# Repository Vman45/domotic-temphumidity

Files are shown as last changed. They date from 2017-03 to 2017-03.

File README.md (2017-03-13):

<!-- TOC depthFrom:1 depthTo:6 withLinks:1 updateOnSave:1 orderedList:0 -->

- [domotic-temphumidity](#domotic-temphumidity)
	- [Description](#description)
	- [Matériel:](#matriel)
	- [Architecture](#architecture)
	- [TODO:](#todo)
		- [Sauvegarde des mesures](#sauvegarde-des-mesures)
		- [Améliorations:](#amliorations)
			- [Home Assistant:](#home-assistant)
				- [automate](#automate)
			- [WeMos D1 Mini:](#wemos-d1-mini)
				- [Consommation d'énergie - deep sleep](#consommation-dnergie-deep-sleep)
				- [Tension de la batterie](#tension-de-la-batterie)
				- [Ajouter Heat Index et Dew Point](#ajouter-heat-index-et-dew-point)
				- [MQTT](#mqtt)
	- [Quelques sources:](#quelques-sources)
	- [Installation stack TICK sur Raspberry Pi 3](#installation-stack-tick-sur-raspberry-pi-3)
		- [Telegraf](#telegraf)
		- [InfluxDB](#influxdb)
		- [Chonograph](#chonograph)
		- [kapacitor](#kapacitor)
	- [Installation de Grafana](#installation-de-grafana)

<!-- /TOC -->

# domotic-temphumidity
## Description
Projet de "domotique" pour prise de température/humidité dans différentes pièces (et à l'extérieur).

## Matériel:
* `WeMos D1 mini v2`
* `DHT22` (module précâblé)
* `DS18B20` (module précâblé)
* Résistances pour _pont diviseur_: `1 KOhms` (R1) et `220 Ohms` (R2)
* 2 batteries de 3.7v type `18650 lithium-ion`
* `battery holder` à 2 emplacements pour batteries 18650
* [ optionel: `WeMos D1 Mini Single Lithium Battery Charging And Battery Boost Shield` ]
* [ optionel (avec shield ci-dessus): `Micro 1.25mm 2-Pin Female Connector Plug` ]

## Architecture
Les mesures sont envoyées vers un _MQTT broker_ (`Mosquitto`) dans différents _topics_.
Les _topics_ de ce broker sont actuellement consommés par `HomeAssistant`.
Les données sont également sauvegardées dans une _TSDB_ (InfluxDB) par `HomeAssistant`.

## TODO:
### Sauvegarde des mesures
La sauvegarde des données dans `InfluxDB` sera revue car `HomeAssistant` ne pousse des données que s'il y a un changement d'état; autrement dit plusieurs valeurs identiques consécutives ne représentent qu'un point de mesure (le 1ier) dans `InfluxDB`.
Idée à mettre en oeuvre:
* utiliser `Telegraf` pour consommer les _topics MQTT_ et pousser les mesures dans `InfluxDB`.
* désactiver le lien entre `HomeAssistant` et `InfluxDB` (config de `HomeAssistant`).

### Améliorations:
#### Home Assistant:
##### automate
Si le service `Updater` détecte une mise à jour disponible, une notification sera crée par le service `notify.notify`.
Si la tension de la batterie est inférieur au seuil configuré, une notification sera envoyée par le service `notifiy.pushbullet` à (par défaut) tous les _devices_ définis dans `PushBullet`.

#### WeMos D1 Mini:
##### Consommation d'énergie - deep sleep
Mettre le WeMos en _deep sleep_ entre 2 prises de mesure.  !! Attention câblage à ajouter entre `RST` et `D0` (aka `GPIO16`) pour permettre l'éveil) !!
Ne pas oublier d'ajouter cette ligne dans la fonction `setup`:
```
  // Connect D0 to RST to wake up
  pinMode(D0, WAKEUP_PULLUP);
```
et bien entendu dans la fonction `loop`:
```
  // convert to microseconds
  ESP.deepSleep(sleepSeconds * 1000000);
```

##### Tension de la batterie
* Mettre le WeMos en _deep sleep_ plus longtemps si le seuil `X` est atteint.
* Si le seuil `Y` (`X > Y`) est atteint soit mettre le WeMos en _deep sleep_ encore lus longtemps soit stopper (si possible) le WeMos.

##### Ajouter Heat Index et Dew Point
* ajouter la lecture ou le calcul de l'index de température (température ressentie)
* ajouter la lecture ou le calcul du point de rosée ()
Voir les articles:
 - http://www.best-microcontroller-projects.com/dht22.html
 - https://github.com/adafruit/DHT-sensor-library/blob/master/examples/DHTtester/DHTtester.ino
 - https://github.com/adafruit/DHT-sensor-library/blob/master/DHT.cpp
 - https://forums.adafruit.com/viewtopic.php?f=25&t=30241#p167348

##### MQTT
Actuellement, chaque mesure est envoyée dans un topic dédié (ex: température du living dans `home/livingroom/temperature`) ce qui se traduit par 3 _publish_ (température, humidité et tension de la batterie).
Améliorations possibles:
* soit regrouper l'envoi de ces 3 mesures dans 1 seul _topic_ (ex: `home/livingroom`) et ensuite décomposer le message en 3 dans `HomeAssistant`.
* soit revoir la nomenclature des _topics_ en y ajoutant un niveau supplémentaire: l'_étage_ (ex: `home/groundfloor/livingroom/temperature`).  Source: http://www.hivemq.com/blog/mqtt-essentials-part-5-mqtt-topics-best-practices

## Quelques sources:
* mon ami Tixu: https://github.com/tixu
* Mesure de la tension: http://www.projetsdiy.fr/mesurer-tension-alimentation-batterie-esp8266-arduino/#.WMXEVlXhCHs
* Utilisation d'un DHT22: http://www.projetsdiy.fr/esp8266-dht22-mqtt-projet-objet-connecte/#.WMXDn1XhCHu
* Utilisation d'un DS18B20: http://www.esp8266learning.com/wemos-mini-ds18b20-temperature-sensor-example.php
* InfluxDB et Telegraf sur Raspberry Pi: http://padcom13.blogspot.be/2015/12/influxdb-telegraf-and-grafana-on.html
* Packages officiels TICK pour ARM:
 - https://dl.influxdata.com/telegraf/releases/telegraf_1.2.1_armhf.deb
 - https://dl.influxdata.com/influxdb/releases/influxdb_1.2.1_armhf.deb
 - https://dl.influxdata.com/chronograf/releases/chronograf_1.2.0~beta4_armhf.deb
 - https://dl.influxdata.com/kapacitor/releases/kapacitor_1.2.0_armhf.deb
* Grafana on Raspberry Pi: https://github.com/fg2it/grafana-on-raspberry

## Installation stack TICK sur Raspberry Pi 3
### Telegraf
```
wget https://dl.influxdata.com/telegraf/releases/telegraf_1.2.1_armhf.deb
sudo dpkg -i telegraf_1.2.1_armhf.deb
```
### InfluxDB
```
wget https://dl.influxdata.com/influxdb/releases/influxdb_1.2.1_armhf.deb
sudo dpkg -i influxdb_1.2.1_armhf.deb
```
### Chonograph
```
wget https://dl.influxdata.com/chronograf/releases/chronograf_1.2.0~beta4_armhf.deb
sudo dpkg -i chronograph_1.2.0~beta4_armhf.deb
```
### kapacitor
```
wget https://dl.influxdata.com/kapacitor/releases/kapacitor_1.2.0_armhf.deb
sudo dpkg -i kapacitor_1.2.0_armhf.deb
```

## Installation de Grafana
Basé sur https://github.com/fg2it/grafana-on-raspberry (releases: https://github.com/fg2it/grafana-on-raspberry/releases)
```
wget https://github.com/fg2it/grafana-on-raspberry/releases/download/v4.1.2/grafana_4.1.2-1487023783_armhf.deb
sudo dpkg -i grafana_4.1.2-1487023783_armhf.deb
sudo apt-get install -f
```

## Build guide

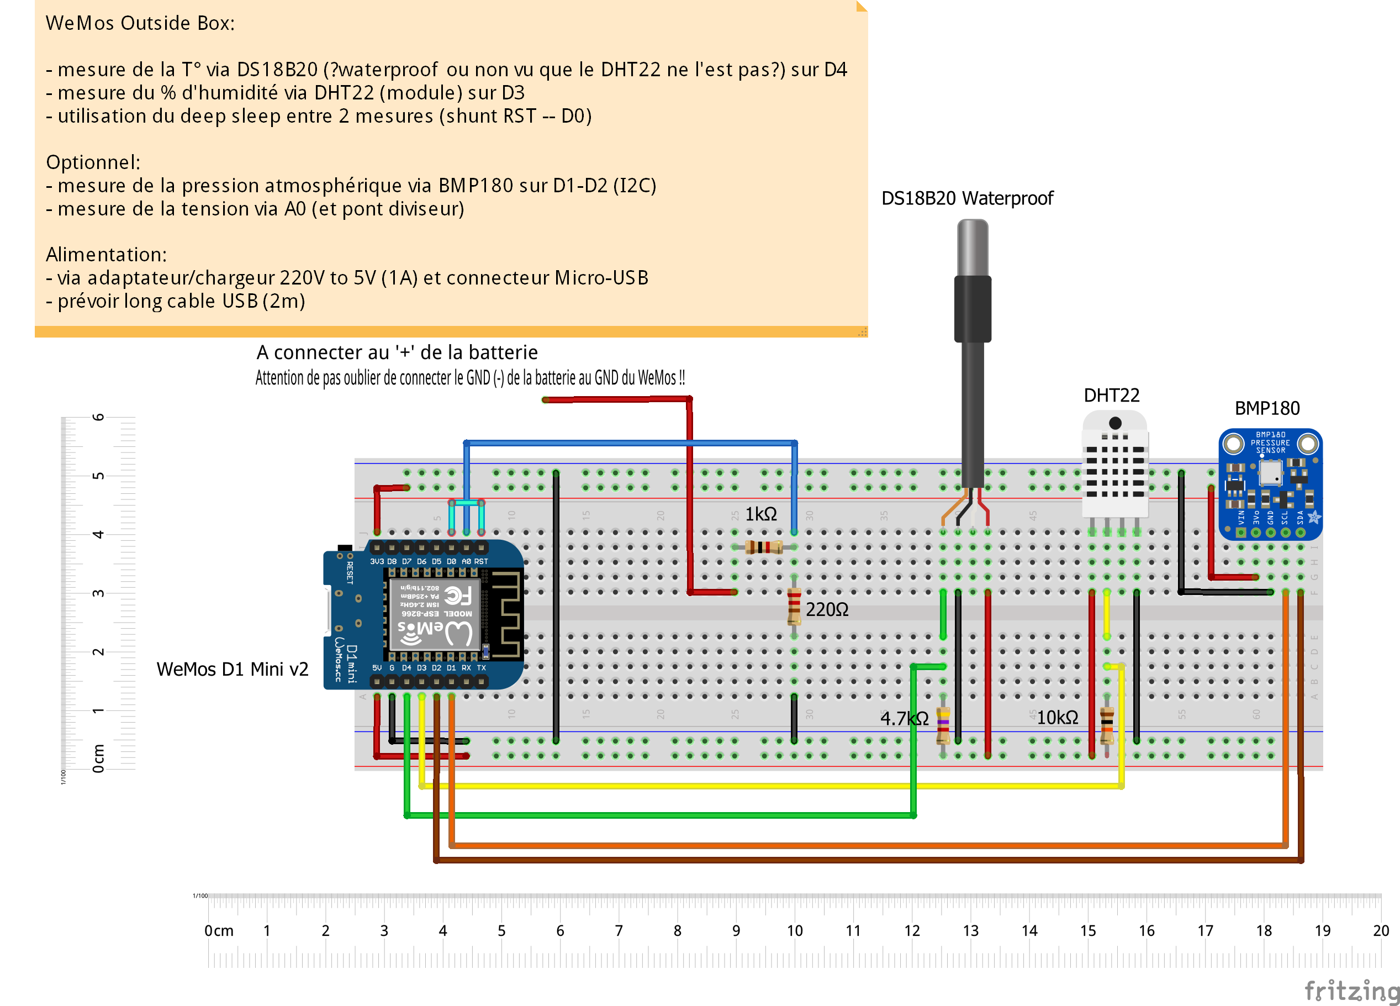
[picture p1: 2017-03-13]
wiring-outside-box.png

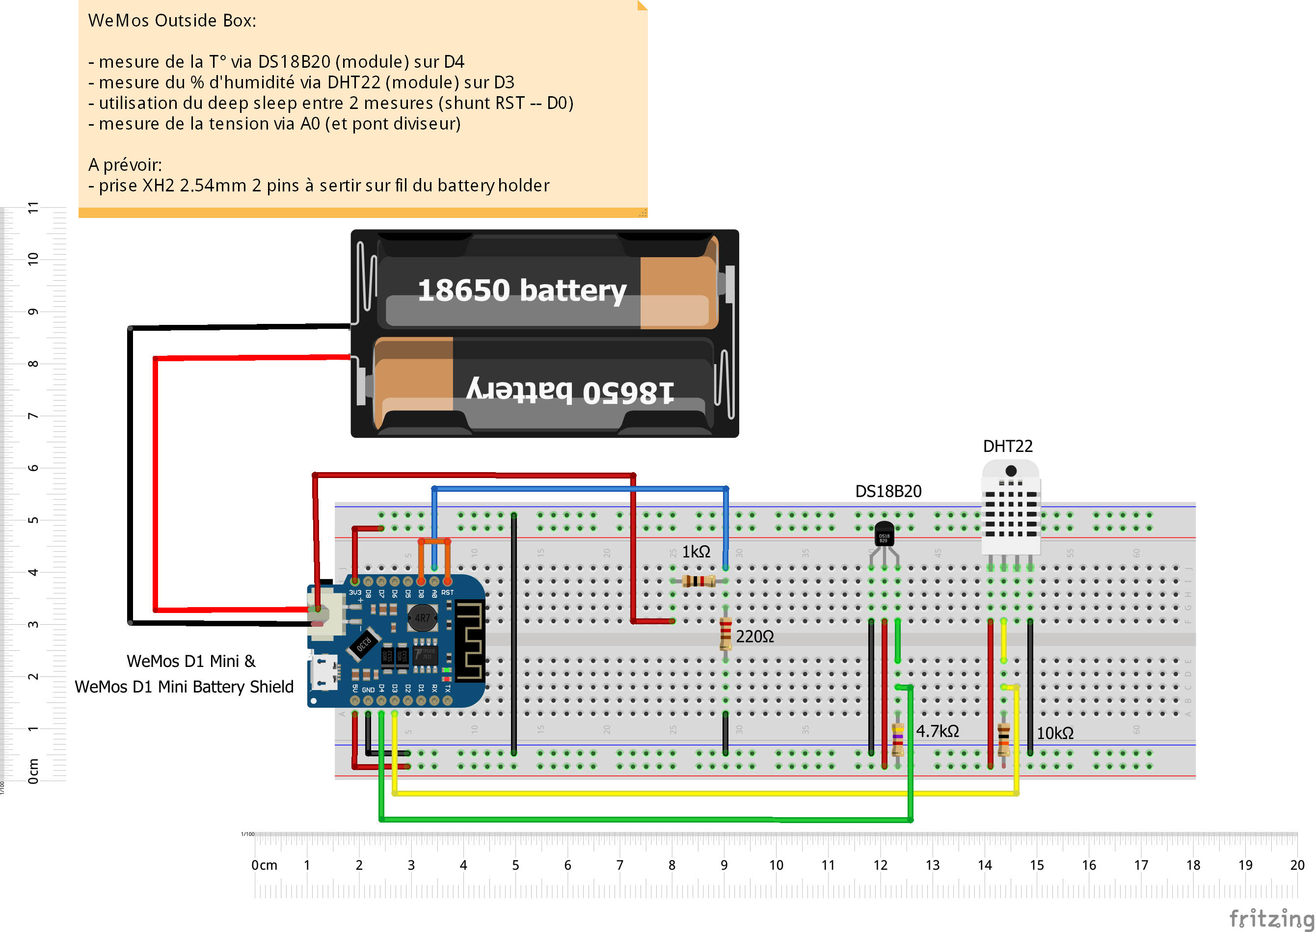
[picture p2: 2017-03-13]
wiring-inside-box.png

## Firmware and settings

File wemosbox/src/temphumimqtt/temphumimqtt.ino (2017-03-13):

// Include the libraries we need
#include <Adafruit_Sensor.h>
#include <DHT.h>

#include <OneWire.h>
#include <DallasTemperature.h>

#include <DNSServer.h>
#include <WiFiClient.h>
#include <ESP8266WebServer.h>
#include <WiFiManager.h>

#include <PubSubClient.h>

#include <ArduinoJson.h>

#define ssid     "" // WiFi SSID
#define password "" // WiFi password


// DHT Config ***************************************************************
// DHT Sensor on pin D3
#define DHTPIN D3
// Using a DHT22 sensor
#define DHTTYPE DHT22

DHT dht(DHTPIN, DHTTYPE);

// MQTT Config **************************************************************
#define mqtt_server    "192.168.1.10"
#define mqtt_port      1883
// #define mqtt_user   "mqtt_user"
// #define mqtt_pass   "mqtt_pass"
#define out_temp_topic "home/livingroom/temperature"
#define out_hum_topic  "home/livingroom/humidity"
#define out_batt_topic "home/livingroom/battery"

// DS18B20 Sensor Config *****************************************************
// Data wire is plugged into port D4 on the WeMos 
// Setup a oneWire instance to communicate with any OneWire devices (not just Maxim/Dallas temperature ICs)
OneWire oneWire(D4);

// Pass our oneWire reference to Dallas Temperature.
DallasTemperature sensors(&oneWire);

// arrays to hold device address
DeviceAddress insideThermometer;

// To handle time between 2 reads
const int sensorPolling = 30000;
unsigned long currentMillis = 0;    // stores the value of millis() in each iteration of loop()
unsigned long previousPoll = 0;   // will store last time the LED was updated

char data[80];

// ESP Config ******************************************************************
WiFiClient espClient;
PubSubClient client(espClient);

// Web server running on port
ESP8266WebServer server (80);

// Measurement *****************************************************************
// Temp
//   - DS18B20
float t = 0;
//   - DHT22
float t2 = 0;
// Humidity
//   - DHT22
float h = 0;

// Battery Voltage
//     Const
const float tMaxA0 = 3.3; // Tmax permissible by the A/D converter on pin A0
const float coeff = 0.18; // Divider bridge coeff in ohms = (R1 / (R1 + R2)) where R1 = 1Kohms and R2 220ohms
const float diff = 0.0;  // = Diff between calculation and voltmeter
//     raw value read from A/D converter
unsigned int raw = 0;
//     real voltage
float batV = 0;


// Setup function. Here we do the basics **************************************
void setup(void) {

  Serial.begin(9600);
  pinMode(BUILTIN_LED, OUTPUT);
  pinMode(A0, INPUT);
  
  Serial.println("Domotic - Temperature and Humidity sensor");
  WiFiManager wifiManager;

  // locate devices on the bus
  Serial.print("Locating devices ... ");
  sensors.begin();
  Serial.print(" Found ");
  Serial.print(sensors.getDeviceCount(), DEC);
  Serial.println(" devices.");

  // report parasite power requirements
  Serial.print("Parasite power is: ");
  if (sensors.isParasitePowerMode()) Serial.println("ON");
  else Serial.println("OFF");

  if (!sensors.getAddress(insideThermometer, 0)) Serial.println("Unable to find address for Device 0");

  Serial.print("Device 0 Address: ");
  printAddress(insideThermometer);
  Serial.println();

  // set the resolution to 9 bit (Each Dallas/Maxim device is capable of several different resolutions)
  sensors.setResolution(insideThermometer, 10);
  Serial.print("Device 0 Resolution: ");
  Serial.print(sensors.getResolution(insideThermometer), DEC);
  Serial.println();

  // Initialize DHT Sensor
  dht.begin();

  wifiManager.autoConnect(ssid, password);
  // Connexion WiFi établie / WiFi connexion is OK
  Serial.println("");
  Serial.print("Connected to "); Serial.println ( ssid );
  Serial.print("IP address: "); Serial.println ( WiFi.localIP() );

  client.setServer(mqtt_server, mqtt_port);
  client.setCallback(callback);

  // On branche la fonction qui gère la premiere page / link to the function that manage launch page
  server.on("/", handleRoot);

  server.begin();
  Serial.println("HTTP server started");
}

// *************************************************************************************************
String getPage() {

  String page = "";
  page += "<!DOCTYPE html>";
  page += "<html lang='en'>";
  page += "  <head>";
  page += "    <meta charset='utf-8'>";
  page += "    <meta http-equiv='X-UA-Compatible' content='IE=edge'>";
  page += "    <meta name='viewport' content='width=device-width, initial-scale=1'>";
  page += "";
  page += "    <title>Wemos D1 Mini Pro</title>";
  page += "";
  page += "    <meta name='description' content='Wemos Test'>";
  page += "    <meta name='author' content='LayoutIt!'>";
  page += "";
  page += "<link rel='stylesheet' href='https://maxcdn.bootstrapcdn.com/bootstrap/3.3.7/css/bootstrap.min.css'></link>";
  page += "<script src='https://ajax.googleapis.com/ajax/libs/jquery/3.1.1/jquery.min.js'></script>";
  page += "<script src='https://maxcdn.bootstrapcdn.com/bootstrap/3.3.7/js/bootstrap.min.js'></script>";
  page += "";
  page += "  </head>";
  page += "  <body>";
  page += "";
  page += "    <div class='container-fluid'>";
  page += "  <div class='row'>";
  page += "   <div class='col-md-12'>";
  page += "     <div class='page-header'>";
  page += "       <h1>";
  page += "         Wemos D1  Mini Pro: Test interface";
  page += "       </h1>";
  page += "     </div>";
  page += "     <ul class='nav nav-pills'>";
  page += "       <li class='active'>";
  page += "          <a href='#'>Temperature : ";
  page += t;
  page += " °C / ";
  page += t2;
  page += " °C";
  page += "</a>";
  page += "       </li>";
  page += "       <li class='active'>";
  page += "          <a href='#'>Humidity : ";
  page += h;
  page += "</a>";
  page += "       </li>";
  page += "     </ul>";
  page += "   </div>";
  page += " </div>";
  page += "</div>";
  page += "";
  page += "    <script src='js/jquery.min.js'></script>";
  page += "    <script src='js/bootstrap.min.js'></script>";
  page += "    <script src='js/scripts.js'></script>";
  page += "  </body>";
  page += "</html>";

  return page;
}

// *******************************************************************************************
void handleRoot() {
  server.send (200, "text/html", getPage());
}

// Publishes temperature to MQTT server *************************************************************  
void publishTemperature(float p_temperature) {

  // create a JSON object
  // doc : https://github.com/bblanchon/ArduinoJson/wiki/API%20Reference
  StaticJsonBuffer<100> jsonBuffer;
  JsonObject& root = jsonBuffer.createObject();
  // INFO: the data must be converted into a string; a problem occurs when using floats...
  root["temperature"] = (String)p_temperature;
  root.prettyPrintTo(Serial);
  Serial.println("");
  /*
     {
        "temperature": "19.40"
     }
  */
  char data[100];
  root.printTo(data, root.measureLength() + 1);
  client.publish(out_temp_topic, data, true);
}

// Publishes humidity to MQTT server *************************************************************  
void publishHumidity(float p_humidity) {

  // create a JSON object
  // doc : https://github.com/bblanchon/ArduinoJson/wiki/API%20Reference
  StaticJsonBuffer<100> jsonBuffer;
  JsonObject& root = jsonBuffer.createObject();
  // INFO: the data must be converted into a string; a problem occurs when using floats...
  root["humidity"] = (String)p_humidity;
  root.prettyPrintTo(Serial);
  Serial.println("");
  /*
     {
        "humidity": "19.40"
     }
  */
  char data[100];
  root.printTo(data, root.measureLength() + 1);
  client.publish(out_hum_topic, data, true);
}

void publishBatteryVoltage(float p_voltage) {
  // create a JSON object
  // doc : https://github.com/bblanchon/ArduinoJson/wiki/API%20Reference
  StaticJsonBuffer<100> jsonBuffer;
  JsonObject& root = jsonBuffer.createObject();
  // INFO: the data must be converted into a string; a problem occurs when using floats...
  root["voltage"] = (String)p_voltage;
  root.prettyPrintTo(Serial);
  Serial.println("");
  /*
     {
        "voltage": "3.79"
     }
  */
  char data[100];
  root.printTo(data, root.measureLength() + 1);
  client.publish(out_batt_topic, data, true);
}

// Main function *****************************************************************************
// Handles time between readings and publishes to MQTT
void loop(void) {

  currentMillis = millis();
  server.handleClient();
  if (!client.connected()) {
    reconnect();
  }
  client.loop();

  // if delay expired then read temp and humidity
  if (currentMillis - previousPoll >= sensorPolling) {
    Serial.print("Requesting temperature ... ");
    sensors.requestTemperatures(); // Send the command to get temperatures
    Serial.println("DONE");
    t = sensors.getTempC(insideThermometer);
    Serial.print("Publishing temperature ... ");
    publishTemperature(t);
    Serial.println("DONE");
    
    Serial.print("Requesting humidity ... ");
    h = dht.readHumidity();
    // t2 = dht.readTemperature();  // ONLY for test (to compare with DS18B20)
    if (isnan(h)) {
      Serial.println("ERROR: Failed to read from DHT sensor!");
      return;
    } else {
      Serial.println("DONE");
      Serial.print("Publishing humidity ... ");
      publishHumidity(h);
      Serial.println("DONE");
    }

    Serial.print("Requesting battery voltage ... ");
    // Reading value vrom A/D converter
    unsigned int raw = analogRead(A0);
    Serial.print("DONE ... raw ");
    Serial.println(raw);
    // Compute the real battery voltage
    float batV = ((raw * (tMaxA0 / 1024)) / coeff) - diff;
    Serial.print("Publishing temperature ... ");
    publishBatteryVoltage(batV);
    Serial.println("DONE");

    previousPoll += sensorPolling;
  }
}

// Prints a device address **************************************************************************
void printAddress(DeviceAddress deviceAddress) {
  
  for (uint8_t i = 0; i < 8; i++) {
    if (deviceAddress[i] < 16) Serial.print("0");
    Serial.print(deviceAddress[i], HEX);
  }
}

// Handles received MQTT message ********************************************************************
void callback(char* topic, byte* payload, unsigned int length) {
}

// Reconnects to MQTT server **************************************************************************
void reconnect() {
  
  // Loop until we're reconnected
  while (!client.connected()) {
    
    Serial.print("Attempting MQTT connection ... ");
    // Create a random client ID
    String clientId = "ESP8266Client-Living";
    clientId += String(random(0xffff), HEX);
    // Attempt to connect
    
    if (client.connect(clientId.c_str())) {
      Serial.println("CONNECTED");
      
    } else {
      Serial.print("Failed, rc=");
      Serial.print(client.state());
      Serial.println(" try again in 5 seconds");
      // Wait 5 seconds before retrying
      delay(5000);
    }
  }
}

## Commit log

2017-03-11 Added configuration for NAS and battery voltage
2017-03-11 Moved and added reading battery voltage on pin A0
2017-03-12 Added automation config about battery voltage
2017-03-12 Added wiring diagram
2017-03-12 Added wiring diagram (fritzing project)
    [fritzing-wiring.fzz]
2017-03-12 Updated automation cconfiguration (battery voltage)
2017-03-13 Spliited outside and inside boxes
    [fritzing-wiring-outside-box.fzz, fritzing-wiring.fzz, wiring-inside-box.fzz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]
2017-03-13 Added infos about installation of TICK & Grafana on a Raspberry Pi
2017-03-13 Renamed file
    [fritzing-wiring-outside-box.fzz]
2017-03-13 Updated DS18B20 pin according to uses of BMP180 on I2C
